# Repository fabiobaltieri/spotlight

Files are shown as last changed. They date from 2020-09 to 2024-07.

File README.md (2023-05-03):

# Spotlight

BLE enabled headlamp and mod boards.

## License (firmware, bootloader, ciq-app)

This program is free software: you can redistribute it and/or modify
it under the terms of the GNU General Public License as published by
the Free Software Foundation, either version 3 of the License, or
(at your option) any later version.

## License (hardware)

Hardware files are licensed under a
Creative Commons Attribution-ShareAlike 4.0 International License.

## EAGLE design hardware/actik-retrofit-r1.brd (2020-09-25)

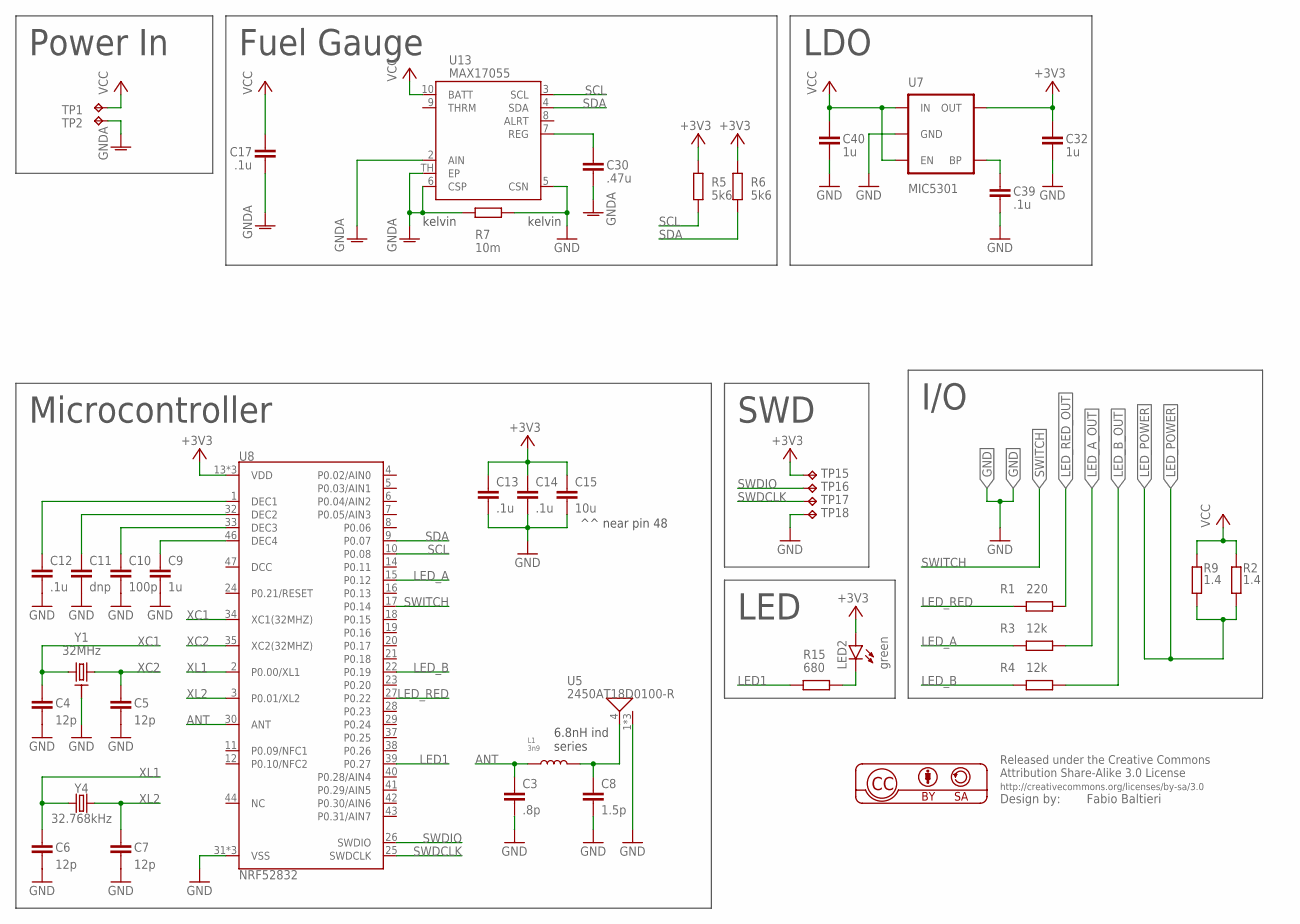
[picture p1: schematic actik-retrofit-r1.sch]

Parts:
C3: .8p; 0603
C4, C5, C6, C7: 12p; 0603
C8: 1.5p; 0603
C9, C32, C40: 1u; 0603
C10: 100p; 0603
C11: dnp; 0603
C12, C13, C14, C17, C39: .1u; 0603
C15: 10u; 0603
C30: .47u; 0603
L1: 3n9; L0603
LED2: green; SML0805
R1: 220; 0603
R2, R9: 1.4; R3225
R3, R4: 12k; 0603
R5, R6: 5k6; 0603
R7: 10m; 0603
R15: 680; 0603
TP1, TP2: TPPAD1-13; P1-13
TP15, TP16, TP17, TP18: TPTP10R; TP10R
U5: 2450AT18D0100-R
U7: MIC5301; SOT23-5
U8: NRF52832; QFN48-6X6MM
U13: MAX17055; TDFN10-2X2.5
Y1: 32MHz; XTAL-2X1.6
Y4: 32.768kHz; CRYSTAL-SMD-3.2X1.5MM

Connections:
+3V3: C13.1, C14.1, C15.1, C32.1, LED2.A, R5.1, R6.1, TP15.TP, U7.5 (OUT), U8.13 (VDD), U8.36 (VDD), U8.48 (VDD)
ANT: C3.1, L1.P$1, U8.30 (ANT)
GND: C3.2, C4.2, C5.2, C6.2, C7.2, C8.2, C9.2, C10.2, C11.2, C12.2, C13.2, C14.2, C15.2, C32.2, C39.2, C40.2, R7.1, TP18.TP, U5.1 (GND), U5.2 (GND), U5.3 (GND), U7.2 (GND), U8.31 (VSS), U8.45 (VSS), U8.EP (VSS), U13.5 (CSN), Y1.2 (GND), Y1.4 (GND)
GNDA: C17.2, C30.2, R7.2, TP2.TP, U13.2 (AIN), U13.6 (CSP), U13.TH (EP)
LED1: R15.2, U8.39 (P0.27)
LED_A: R3.2, U8.15 (P0.12)
LED_A_OUT: R3.1
LED_B: R4.2, U8.22 (P0.19)
LED_B_OUT: R4.1
LED_POWER: R2.2, R9.2
LED_RED: R1.2, U8.27 (P0.22)
LED_RED_OUT: R1.1
unnamed: C8.1, L1.P$2, U5.4 (FEED)
unnamed: C9.1, U8.46 (DEC4)
unnamed: C10.1, U8.33 (DEC3)
unnamed: C11.1, U8.32 (DEC2)
unnamed: C12.1, U8.1 (DEC1)
unnamed: LED2.C, R15.1
unnamed: C39.1, U7.4 (BP)
unnamed: C30.1, U13.7 (REG)
SCL: R5.2, U8.10 (P0.08), U13.3 (SCL)
SDA: R6.2, U8.9 (P0.07), U13.4 (SDA)
SWDCLK: TP17.TP, U8.25 (SWDCLK)
SWDIO: TP16.TP, U8.26 (SWDIO)
SWITCH: U8.17 (P0.14)
VCC: C17.1, C40.1, R2.1, R9.1, TP1.TP, U7.1 (IN), U7.3 (EN), U13.10 (BATT)
XC1: C4.1, U8.34 (XC1(32MHZ)), Y1.1
XC2: C5.1, U8.35 (XC2(32MHZ)), Y1.3 (2)
XL1: C6.1, U8.2 (P0.00/XL1), Y4.P$1 (1)
XL2: C7.1, U8.3 (P0.01/XL2), Y4.P$2 (2)

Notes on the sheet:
LDO
LED
SWD
I/O
Power In
Microcontroller
^^ near pin 48
Fuel Gauge
kelvin
6.8nH ind series

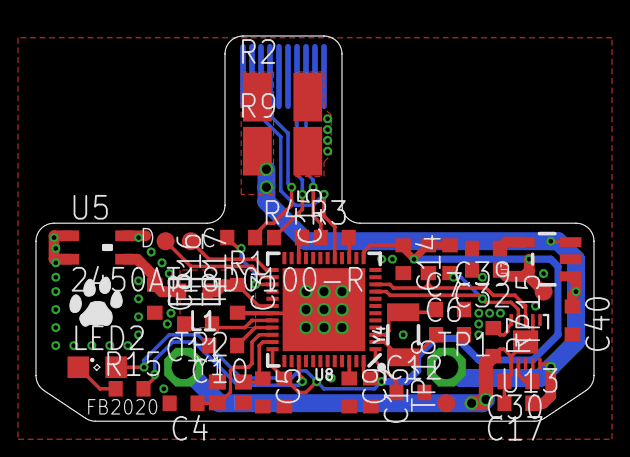
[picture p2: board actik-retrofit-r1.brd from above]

Board: 2 copper layers, 31.0 x 21.4 mm, 42 parts (0 on the bottom side), 26 nets.

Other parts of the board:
U$1: CAT-L

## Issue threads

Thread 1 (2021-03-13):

Is there a page that describes better this project?

casainho, 2021-03-13:
For what I can understand, there is an hardware, firmware (probably NRF52xxx) and then a Garmin CIQ. I wish I could see more details of all this, lime some pictures.

I am trying to develop a firmware for a NRF52840 board to send data by ANT to Garmin Edge, to have several data fields, each one connecting to a unique ANT channel and receive data from an EBike that uses the NRF52840 board. I think I will learn a lot with this project, thanks for sharing!!!!!

And here the link for our OpenSource EBike project in case you are curious: https://opensourceebike.github.io/

fabiobaltieri, 2021-03-14:
HI! Yeah the project probably deserves a bit of a writeup, the bit that turned out to be practical is the actik-retrofit-r1 in hardware, I posted a couple of pictures here: https://fabiobaltieri.com/2019/09/21/design-analysis-of-a-petzl-actik-core-headlamp/, unfortunately though it's incredibly tedious to solder to the LED board.

There's still some useful stuff in the code, the communication part is pretty much self contained in firmware/telemetry.c and ciq-app/source/AntDevice.mc. Out of the box it builds for the nRF52832 it should be easy to port to any other nRF52.

The CIQ Datafield APIs don't really give you a way to connect one custom ANT device and use it in multiple datafields, so yeah you could use one ANT channel per field but frankly that's pretty ugly (more power consumption, more channel collisions, channels are limited etc...). You'd probably be better off doing a datafield that detects when it's placed on a large slot and displays multiple values.

Good luck!

casainho, 2021-03-14:
Meanwhile I found your site and your Youtube and I could figure out :-)

So, thanks to your code I was able to have for testing 2 data fields with his own unique ANT channel and it works well as expected. I am now blocked because I am also using ANT+ LEV and for some reason if I enable ANT+ LEV it works but the ANT generic channels stop to work... eheh :-)

So on your Youtube I see a video of lights wireless controlled on your bicycle helmet and now the control of the head lamps... so cycling and trail run!! that is something I am being enjoying also!! I am developing OpenSource EBike technology and knowledge over the years but I wish to be involved in future on "ELegs", the same concept as EBike but for running in outdoors - you know, exeskeleton but with focus on sports, to help people go more outside to mountains!!

Closed 2021-03-14.

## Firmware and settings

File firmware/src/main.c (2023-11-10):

#include <zephyr/device.h>
#include <zephyr/devicetree.h>
#include <zephyr/drivers/led.h>
#include <zephyr/kernel.h>
#include <zephyr/logging/log.h>

#include "levels.h"
#include "state.h"

LOG_MODULE_REGISTER(main, LOG_LEVEL_INF);

#if DT_HAS_COMPAT_STATUS_OKAY(nordic_nrf52_dk_nrf52832)
#warning "building for nRF52DK"
#endif

struct state state;

static const struct device *leds = DEVICE_DT_GET_ONE(gpio_leds);

static K_TIMER_DEFINE(blink_sync, NULL, NULL);

static void battery_blink(void)
{
	int i;
	int blinks;

	blinks = CLAMP((state.soc / 25) + 1, 1, 4);
	for (i = 0; i < blinks; i++) {
		led_on(leds, 0);
		k_sleep(K_MSEC(10));
		led_off(leds, 0);
		k_sleep(K_MSEC(300));
	}
}

int main(void)
{
	if (!device_is_ready(leds)) {
		LOG_ERR("LED device is not ready");
		return 0;
	}

	levels_hello();

	k_timer_start(&blink_sync, K_SECONDS(3), K_SECONDS(3));

	for (;;) {
		if (state.mode != MODE_SHUTDOWN) {
			battery_blink();
		}
		k_timer_status_sync(&blink_sync);
	}

	return 0;
}

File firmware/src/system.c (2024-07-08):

#include <zephyr/device.h>
#include <zephyr/devicetree.h>
#include <zephyr/drivers/gpio.h>
#include <zephyr/drivers/sensor.h>
#include <zephyr/drivers/sensor/max17055.h>
#include <zephyr/kernel.h>
#include <zephyr/logging/log.h>
#include <zephyr/sys/poweroff.h>

#include "ble.h"
#include "levels.h"
#include "state.h"

LOG_MODULE_REGISTER(system, LOG_LEVEL_INF);

static K_TIMER_DEFINE(system_sync, NULL, NULL);

#define SHUTDOWN_DELAY (60 * 30)

static const struct device *fuel_gauge = DEVICE_DT_GET_ONE(maxim_max17055);
static const struct device *temp = DEVICE_DT_GET_ONE(nordic_nrf_temp);

static const struct gpio_dt_spec wkup = GPIO_DT_SPEC_GET(DT_NODELABEL(wkup), gpios);

static void maybe_shutdown(void)
{
	static uint16_t shutdown_counter = SHUTDOWN_DELAY;

	if (state.mode != MODE_STANDBY) {
		shutdown_counter = SHUTDOWN_DELAY;
		return;
	}

	LOG_INF("shutdown_counter: %d", shutdown_counter);
	if (shutdown_counter--)
		return;

	LOG_INF("initiate shutdown");

	gpio_pin_configure_dt(&wkup, GPIO_INPUT);
	gpio_pin_interrupt_configure_dt(&wkup, GPIO_INT_LEVEL_ACTIVE);

	state.mode = MODE_SHUTDOWN;

	k_sleep(K_SECONDS(3));

	sys_poweroff();
}

#define RESERVE_MV 2800
static void maybe_reserve(void)
{
	if (state.level != LEVEL_HIGH)
		return;

	if (state.batt_mv > RESERVE_MV)
		return;

	state.level = LEVEL_MEDIUM;
	levels_apply_state();
}

static void fuel_gauge_update(void)
{
	struct sensor_value val;
	int32_t tte;

	sensor_sample_fetch_chan(fuel_gauge, SENSOR_CHAN_GAUGE_STATE_OF_CHARGE);
	sensor_sample_fetch_chan(fuel_gauge, SENSOR_CHAN_MAX17055_VFOCV);
	sensor_sample_fetch_chan(fuel_gauge, SENSOR_CHAN_GAUGE_TIME_TO_EMPTY);

	sensor_channel_get(fuel_gauge, SENSOR_CHAN_GAUGE_STATE_OF_CHARGE, &val);
	state.soc = val.val1;

	sensor_channel_get(fuel_gauge, SENSOR_CHAN_MAX17055_VFOCV, &val);
	state.batt_mv = val.val1 * 1000 + val.val2 / 1000;

	sensor_channel_get(fuel_gauge, SENSOR_CHAN_GAUGE_TIME_TO_EMPTY, &val);
	tte = val.val1;
	if (tte > UINT8_MAX)
		state.tte = UINT8_MAX;
	else
		state.tte = tte;
}

static void temp_update(void)
{
	struct sensor_value val;

	sensor_sample_fetch(temp);

	sensor_channel_get(temp, SENSOR_CHAN_DIE_TEMP, &val);

	state.temp = val.val1;
}

#define R_BATT 0.36f
#define V_LED_EQ 2.70f
#define R_LED_EQ 0.50f
#define R_SHUNT 0.7f
#define P_TARGET_HIGH 1.5f
#define P_TARGET_LOW 0.75f
static void dc_update(void)
{
	float vbatt;
	float i;
	float pled100;
	float dc;
	float p_target;

	if (state.level == LEVEL_HIGH)
		p_target = P_TARGET_HIGH;
	else
		p_target = P_TARGET_LOW;

	vbatt = state.batt_mv;
	i = (vbatt / 1000.0f - V_LED_EQ) / (R_BATT + R_LED_EQ + R_SHUNT);
	pled100 = (V_LED_EQ + R_LED_EQ * i) * i;
	dc = p_target / pled100 * 100;

	if (dc > 100)
		dc = 100;

	state.dc = dc;
}

static void system_loop(void)
{
	maybe_shutdown();
	maybe_reserve();
	fuel_gauge_update();
	temp_update();
	dc_update();
	ble_update();

	levels_apply_state();

}

static void system_thread(void)
{
	if (!device_is_ready(fuel_gauge)) {
		LOG_ERR("fuel gauge device is not ready");
		return;
	}

	if (!device_is_ready(temp)) {
		LOG_ERR("temp device is not ready");
		return;
	}

	k_timer_start(&system_sync, K_SECONDS(1), K_SECONDS(1));

	for (;;) {
		system_loop();
		k_timer_status_sync(&system_sync);
	}
}

K_THREAD_DEFINE(sys, 1024, system_thread, NULL, NULL, NULL, 7, 0, 0);

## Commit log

2019-02-19 spotlight: rev0
    [spotlight.brd, spotlight.sch]
2019-02-19 power: wip
    [power.brd, power.sch]
2019-05-04 power: power routed, control placed
    [power.brd, power.sch]
2019-05-04 power: add inner layers
    [power.brd]
2019-07-02 power: r0?
    [power.brd, power.sch]
2019-09-15 power: schematic refactoring?
    [power.brd, power.sch]
2019-09-18 power: few assembly notes
    [power.brd, power.sch]
2019-10-22 hw: add few assembly notes and values
    [power.brd, power.sch, spotlight.sch]
2019-10-22 rename hw -> hardware
    [power.brd, power.sch, spotlight.brd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]
2019-10-23 fw: bunch of init stuff and buttons and LEDs working
2019-10-23 fw: add pwm support
2019-10-23 fw: missing static on bsp_event_handler
    [main.c]
2019-10-24 fw: add i2c support
2019-10-24 fw: a timer, just for fun
2019-10-27 fw: disable pwr mgmt debug pin
2019-10-27 fw: add power board ping mapping
2019-10-27 fw: add config for power led polarity
2019-10-27 fw: debug led shuffle, lower pwm init value
2019-10-27 fw: move pwm setup on its own function
2019-10-27 fw: actually set pwm levels
2019-10-27 fw: add a debug log line for tx collision
    [main.c]
2019-10-28 fw: fix wrong payload dump annotation
    [main.c]
2019-10-28 fw: add temperature sensor reading
2019-10-28 fw: add few comments on the timer start code
2019-10-28 fw: pwm_update, reverse the return logic
    [main.c]
2019-10-28 fw: move pwm adjust to utils
2019-10-28 fw: movw temp i2c code to a separate driver file
2019-10-28 fw: move timer defs at the top
2019-10-28 fw: clean error def from ant_tx_load
    [main.c]
2019-10-30 fw: add missing (void) in timer_init
    [main.c]
2019-10-30 fw: shuffle init around, twi before timer
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2019-10-30 fw: initial mode switching code
    TODO: smarter fallback strategy
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2019-10-31 fw: skip tx load if payload has not changed
    [main.c]
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2019-11-01 fw: use led 0 to indicate remote status
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2019-11-02 fw: add battery voltage reporting (not quite percentage yet)
2019-11-04 fw: add a switch delay timer
    Switch from high to medium and beam to medium on idle, out of auto in
    medium
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2019-11-04 fw: probe the internal temperature sensor for no good reason
2019-11-22 fw: decreae button delay to 2 seconds, reasons
2019-12-04 hw: add tikkina retrofit design
    [tk-retrofit.brd, tk-retrofit.sch]
2019-12-15 fw: only use the two front sensor for temperature
    ...and still use the die sensor on the dev board.
2020-03-22 tk-retrofit: fix ldo p/n
    [tk-retrofit.brd, tk-retrofit.sch]
2020-03-22 ciq: drop the 5V special case, who cares.
2020-03-22 fw: rework the target selection logic to have multiple choices
    [main.c]
2020-03-22 fw: add feature checks for remote, ext temp and pwm
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2020-03-22 ciq: show the device id for a second
2020-03-22 remote: target name and coding style fixes
    [main.c]
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2020-04-07 ciq: only set deviceNum on broadcast data
    ...it's null for channel event messages
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2020-04-07 ciq: switch upload data to page format as well
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2020-04-10 hw: tk-retrofit: change xtal cap values
    [tk-retrofit.brd, tk-retrofit.sch]
2020-04-13 hw: actik-retrofit: first candidate
    [actik-retrofit.brd, actik-retrofit.sch]
2020-04-13 hw: actik-retrofit: sent to fab, r0
    [actik-retrofit.brd, actik-retrofit.sch]
2020-04-15 hw: actik-retrofit: add xtal missing value
    [actik-retrofit.brd, actik-retrofit.sch]
2020-04-18 hw: show inductor value on the antenna line
    [actik-retrofit.sch]
2020-05-24 bl: add board settings from the main firmware
2020-05-24 bl: clean error functions, use only one led
    [main.c]
2020-05-30 hw: actik: annotate the main decoupling cap
    [actik-retrofit.brd, actik-retrofit.sch]
2020-06-09 hw: actik: change few R values
    [actik-retrofit.brd, actik-retrofit.sch]
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2020-06-13 fw: add a set of pwm levels for the actik
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2020-06-14 fw: change adc gain, get a bit more resolution
2020-06-18 fw: replace targets defs to #ifdefs
    [levels.c, system.c]
2020-06-18 fw: add some semi wonky state of charge estimation function
2020-06-19 hw: rename actik-retrofit into actik-retrofit-r0
    [actik-retrofit-r0.brd, actik-retrofit-r0.sch]
2020-06-22 hw: add actik-retrofit-r1
    [actik-retrofit-r1.brd, actik-retrofit-r1.sch]
2020-06-22 hw: actik-r1: change a polygon, few couple nets width
    [actik-retrofit-r1.brd, actik-retrofit-r1.sch]
2020-07-12 hw: change few values
    [actik-retrofit-r1.brd, actik-retrofit-r1.sch]
2020-07-27 hw: actik-r1 set red led res value
    [actik-retrofit-r1.brd, actik-retrofit-r1.sch]
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2020-07-28 fw: add TARGET_HAS_FUEL_GAUGE definition
    Just shut off the adc for the moment.
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2020-08-15 fw: enter reserve based on cell voltage on actik
2020-08-17 fw: switch to twim, define twi instance externally
2020-08-22 ciq: only initialize the fit fields after seeing the device the first time
2020-09-25 hw: actik-r1: annotate schematics for antenna tuning values
    [actik-retrofit-r1.brd, actik-retrofit-r1.sch]
2020-09-25 fw,bl,ciq: switch telemetry to chan 58 devtype 7b and 7c
2020-10-08 fw: telemetry: blink the led with a timer, remove the delay
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2021-01-30 levels: set high strenght high drive on the red led pin
2021-04-02 hw: drop retrofit r0 files
    [actik-retrofit-r0.brd, actik-retrofit-r0.sch]
2021-04-02 hw: drop tk-retrofit files
    [tk-retrofit.brd, tk-retrofit.sch]
2021-04-02 update libraries and licence text
    [actik-retrofit-r1.sch, power.brd, power.sch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]
2021-04-13 ciq-app: add a ant data debug print, commented out by default
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2021-08-30 fw: report calculated ocv rather than actual voltage
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2021-10-26 fw: add and switch to constant power mode
2022-07-12 zfw: set the invert property for the pwm group
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2022-07-24 zfw: simplify dts, add error handling, button event hack
    [main.c]
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2022-07-24 zfw: give button and system thread a bit more stack
2022-07-24 zfw: add few missing static qualifiers
    [main.c, system.c]
2022-07-25 zfw: mystery gpio pin interrupt flag now works... go figure
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2022-07-27 zfw: fix tte units
    [system.c]
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2022-07-27 zfw: add full name in the device ad
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2023-05-03 fw: drop the old power/spotlight hw files
    [power.brd, power.sch, spotlight.brd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]
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2023-10-09 fw: update the button wakeup api to not use the hal
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2024-01-29 fw: fix a double promotion warning
    [system.c]
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

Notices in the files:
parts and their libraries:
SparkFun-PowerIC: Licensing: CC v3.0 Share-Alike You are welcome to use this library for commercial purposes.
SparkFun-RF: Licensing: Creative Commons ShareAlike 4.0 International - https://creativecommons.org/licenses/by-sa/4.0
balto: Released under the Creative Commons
